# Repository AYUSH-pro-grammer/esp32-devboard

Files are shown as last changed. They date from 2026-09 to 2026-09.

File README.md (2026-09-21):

# ESP32-S2 Development Board

Development board built using Espressif ESP32-S2FH4 with USB-C, two WS2812B LEDs, 3.3V LDO and GPIO headers, which have 15 pins on both sides.

## Reasons for creating this project

I created this board because I want to get experience in designing a PCB and build my own ESP32 board. I was interested in building the schematic, routing the PCB and putting everything together.

### How it works

The board receives 5V from USB-C port and uses 3.3V LDO to power the ESP32-S2 module.
The ESP32-S2 is the core part of the board and can be programmed through USB-C.
GPIO pins are routed to two 1x15 headers to use them with jumper wires and breadboard.
WS2812B LEDs and a button were used to add some functionality to the board.

### 3D Model
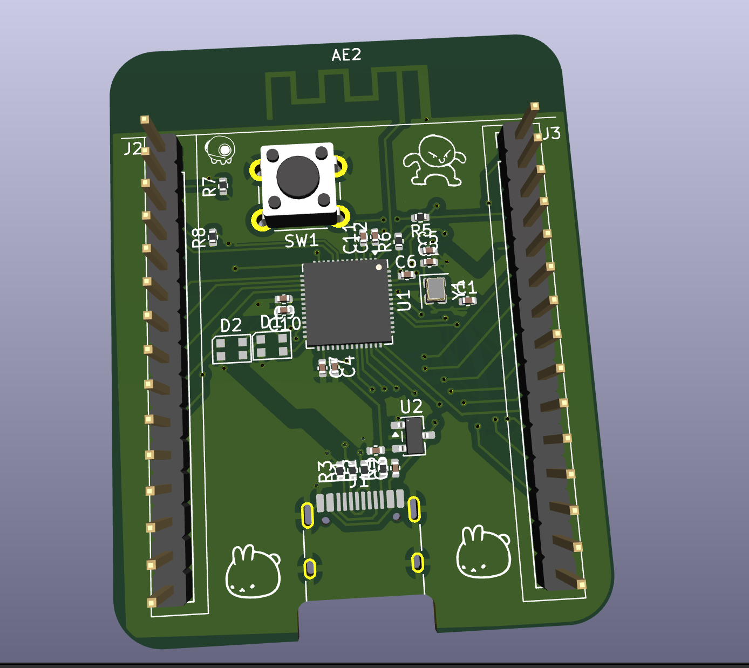
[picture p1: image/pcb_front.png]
PCB Front

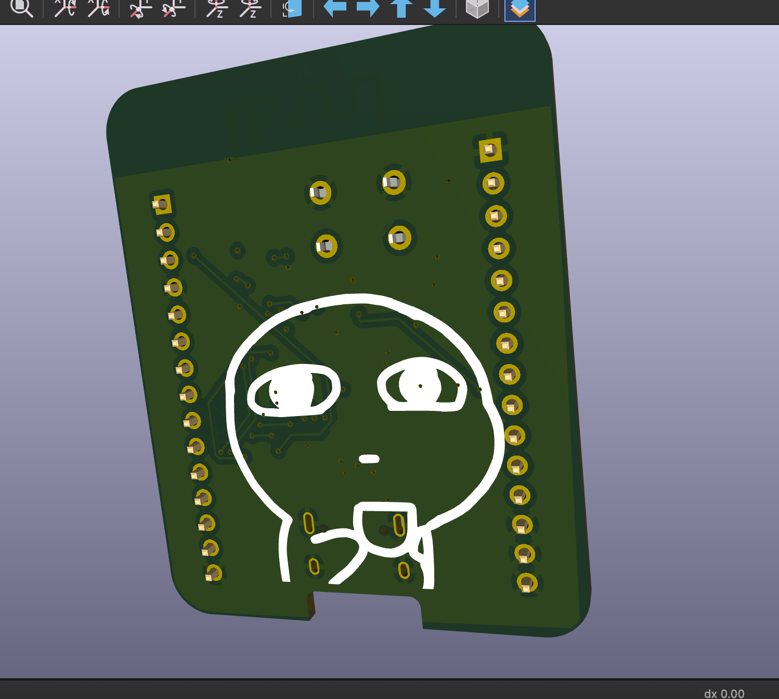
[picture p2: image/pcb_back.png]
PCB Back


### Schematics & Routing
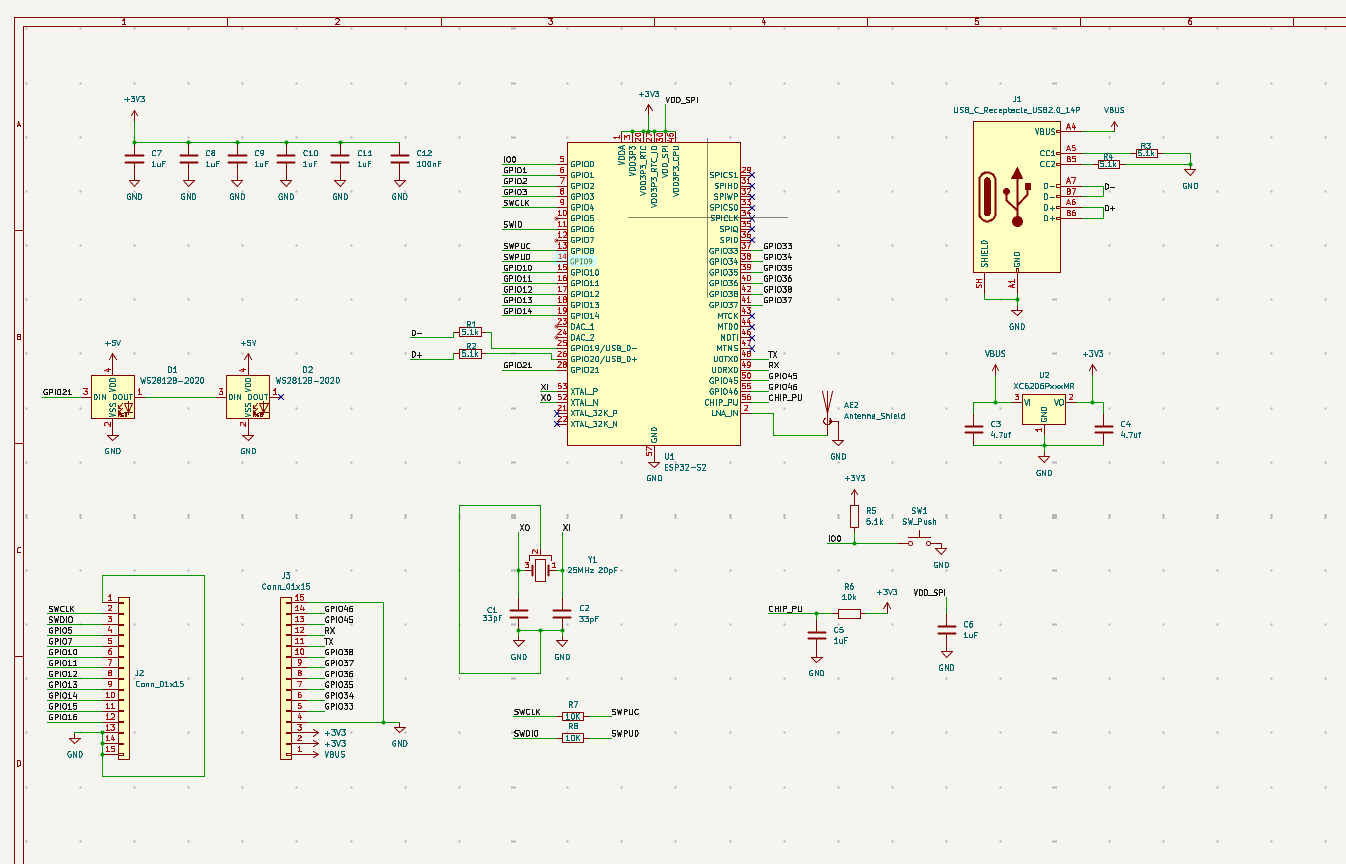
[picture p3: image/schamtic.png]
Schematic

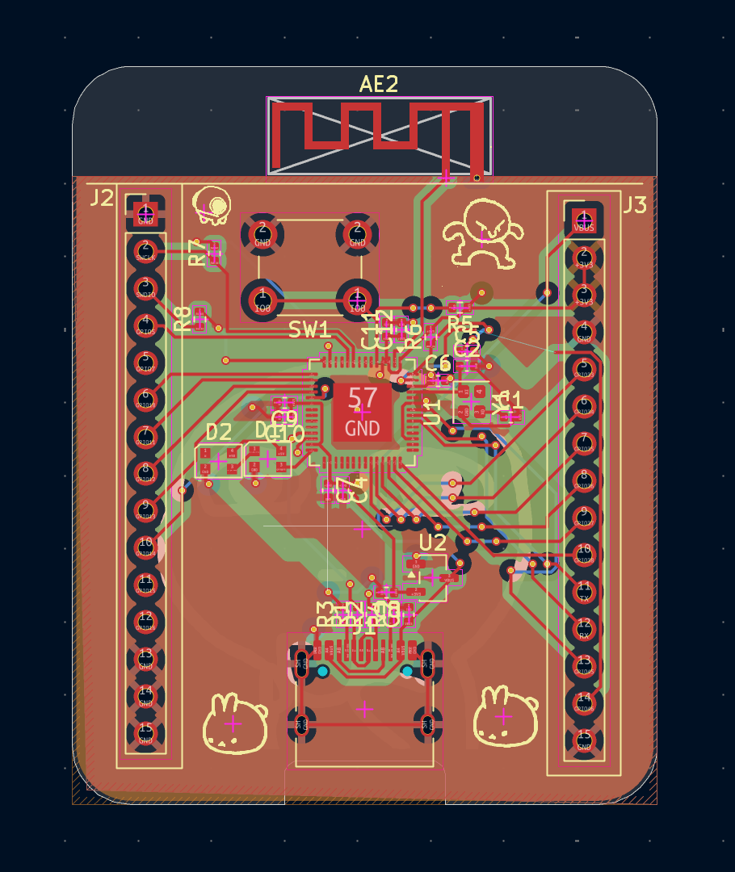
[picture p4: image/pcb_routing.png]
PCB Routing


## BOM Summary

| Qty | Component | Selected Part | Supplier | Link | MOQ | Unit Price (USD) | Order Cost (USD) |
| --: | --- | --- | --- | --- | --: | ---: | ---: |
| 1 | 25 MHz Crystal, 20 pF | SJK 7F25000E20UCG | SJK | [C252274](https://www.lcsc.com/product-detail/C252274.html) | 5 | $0.1139 | $0.57 |
| 2 | 33 pF Capacitor | FOJAN FCC0402N330J500AT | FOJAN | [C5137486](https://www.lcsc.com/product-detail/C5137486.html) | 100 | $0.0030 | $0.30 |
| 1 | 100 nF Capacitor | Samsung Electro-Mechanics CL05B104KO5NNNC | Samsung Electro-Mechanics | [C1525](https://www.lcsc.com/product-detail/C1525.html) | 100 | $0.0046 | $0.46 |
| 7 | 1 µF Capacitor | Samsung Electro-Mechanics CL05A105KA5NQNC | Samsung Electro-Mechanics | [C52923](https://www.lcsc.com/product-detail/C52923.html) |  50 | $0.0100 | $0.50 |
| 2 | 4.7 µF Capacitor | Samsung Electro-Mechanics CL05A475MP5NRNC | Samsung Electro-Mechanics | [C23733](https://www.lcsc.com/product-detail/C23733.html) |  50 | $0.0167 | $0.84 |
| 2 | WS2812B-2020 LED | XINGLIGHT XL-2020RGBC-2812B | XINGLIGHT | [C5349955](https://www.lcsc.com/product-detail/C5349955.html) | 5 | $0.1112 | $0.56 |
| 1 | 1 A / 12 V Resettable Fuse | R+O SMD0805-100-12 | R+O | [C46640991](https://www.lcsc.com/product-detail/C46640991.html) |  10 | $0.0435 | $0.44 |
| 1 | USB-C Receptacle | SHOU HAN TYPE-C16PIN | SHOU HAN | [C393939](https://www.lcsc.com/product-detail/C393939.html) |  10 | $0.0592 | $0.59 |
| 5 | 5.1 kΩ Resistor | UNI-ROYAL 0402WGF5101TCE | UNI-ROYAL | [C25905](https://www.lcsc.com/product-detail/C25905.html) | 100 | $0.0023 | $0.23 |
| 3 | 10 kΩ Resistor | UNI-ROYAL 0402WGF1002TCE | UNI-ROYAL | [C25744](https://www.lcsc.com/product-detail/C25744.html) | 100 | $0.0034 | $0.34 |
| 1 | Tactile Push Button | XUNPU TS-1088-AR02016 | XUNPU | [C720477](https://www.lcsc.com/product-detail/C720477.html) |  10 | $0.0516 | $0.52 |
| 1 | ESP32-S2FH4 | ESPRESSIF ESP32-S2FH4 | ESPRESSIF | [C2840995](https://www.lcsc.com/product-detail/C2840995.html) | 1 | $2.4574 | $2.46 |
| 1 | 3.3 V LDO | TOREX XC6206P332MR-G | TOREX | [C5446](https://www.lcsc.com/product-detail/C5446.html) | 5 | $0.1437 | $0.72 |

## Total

** BOM Total: $8.53 USD**

## Parts

| Designator | Part |
| --- | --- |
| C1, C2 | 33 pF |
| C3, C4, C5, C6, C7, C8, C9 | 1 µF |
| C10 | 100 nF |
| C39, C40 | 4.7 µF |
| D1, D2 | WS2812B-2020 |
| F1 | Resettable Fuse |
| J1 | USB-C Receptacle |
| R1, R2, R3, R4, R5 | 5.1 kΩ |
| R6, R7, R8 | 10 kΩ |
| SW1 | Tactile Push Button |
| U1 | ESP32-S2FH4 |
| U2 | XC6206P332MR-G |
| Y1 | 25 MHz Crystal |

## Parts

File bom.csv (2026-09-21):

SNO. | Quantity | Part Name | Link
0 | 2 | 33pF Capacitor SMD (0402) | https://www.lcsc.com/product-detail/C5137486.html
1 | 1 | 100nF Capacitor SMD (0402) | https://www.lcsc.com/product-detail/C1525.html
2 | 7 | 1uF Capacitor SMD (0402) | https://www.lcsc.com/product-detail/C52923.html
3 | 2 | 4.7uF Capacitor SMD (0402) | https://www.lcsc.com/product-detail/C23733.html
4 | 2 | WS2812B-2020 Addressable RGB LED | https://www.lcsc.com/product-detail/C5349955.html
5 | 1 | 12V 1A Resettable Fuse SMD (0805) | https://www.lcsc.com/product-detail/C46640991.html
6 | 1 | USB-C Receptacle USB 2.0 16-Pin | https://www.lcsc.com/product-detail/C393939.html
7 | 5 | 5.1kΩ Resistor SMD (0402) | https://www.lcsc.com/product-detail/C25905.html
8 | 3 | 10kΩ Resistor SMD (0402) | https://www.lcsc.com/product-detail/C25744.html
9 | 1 | TS-1088-AR02016 Tactile Switch | https://www.lcsc.com/product-detail/C720477.html
10 | 1 | ESP32-S2FH4 | https://www.lcsc.com/product-detail/C2840995.html
11 | 1 | XC6206P332MR-G 3.3V LDO Voltage Regulator (SOT-23-3) | https://www.lcsc.com/product-detail/C5446.html
12 | 1 | 25MHz 20pF Crystal SMD (2016) | https://www.lcsc.com/product-detail/C252274.html

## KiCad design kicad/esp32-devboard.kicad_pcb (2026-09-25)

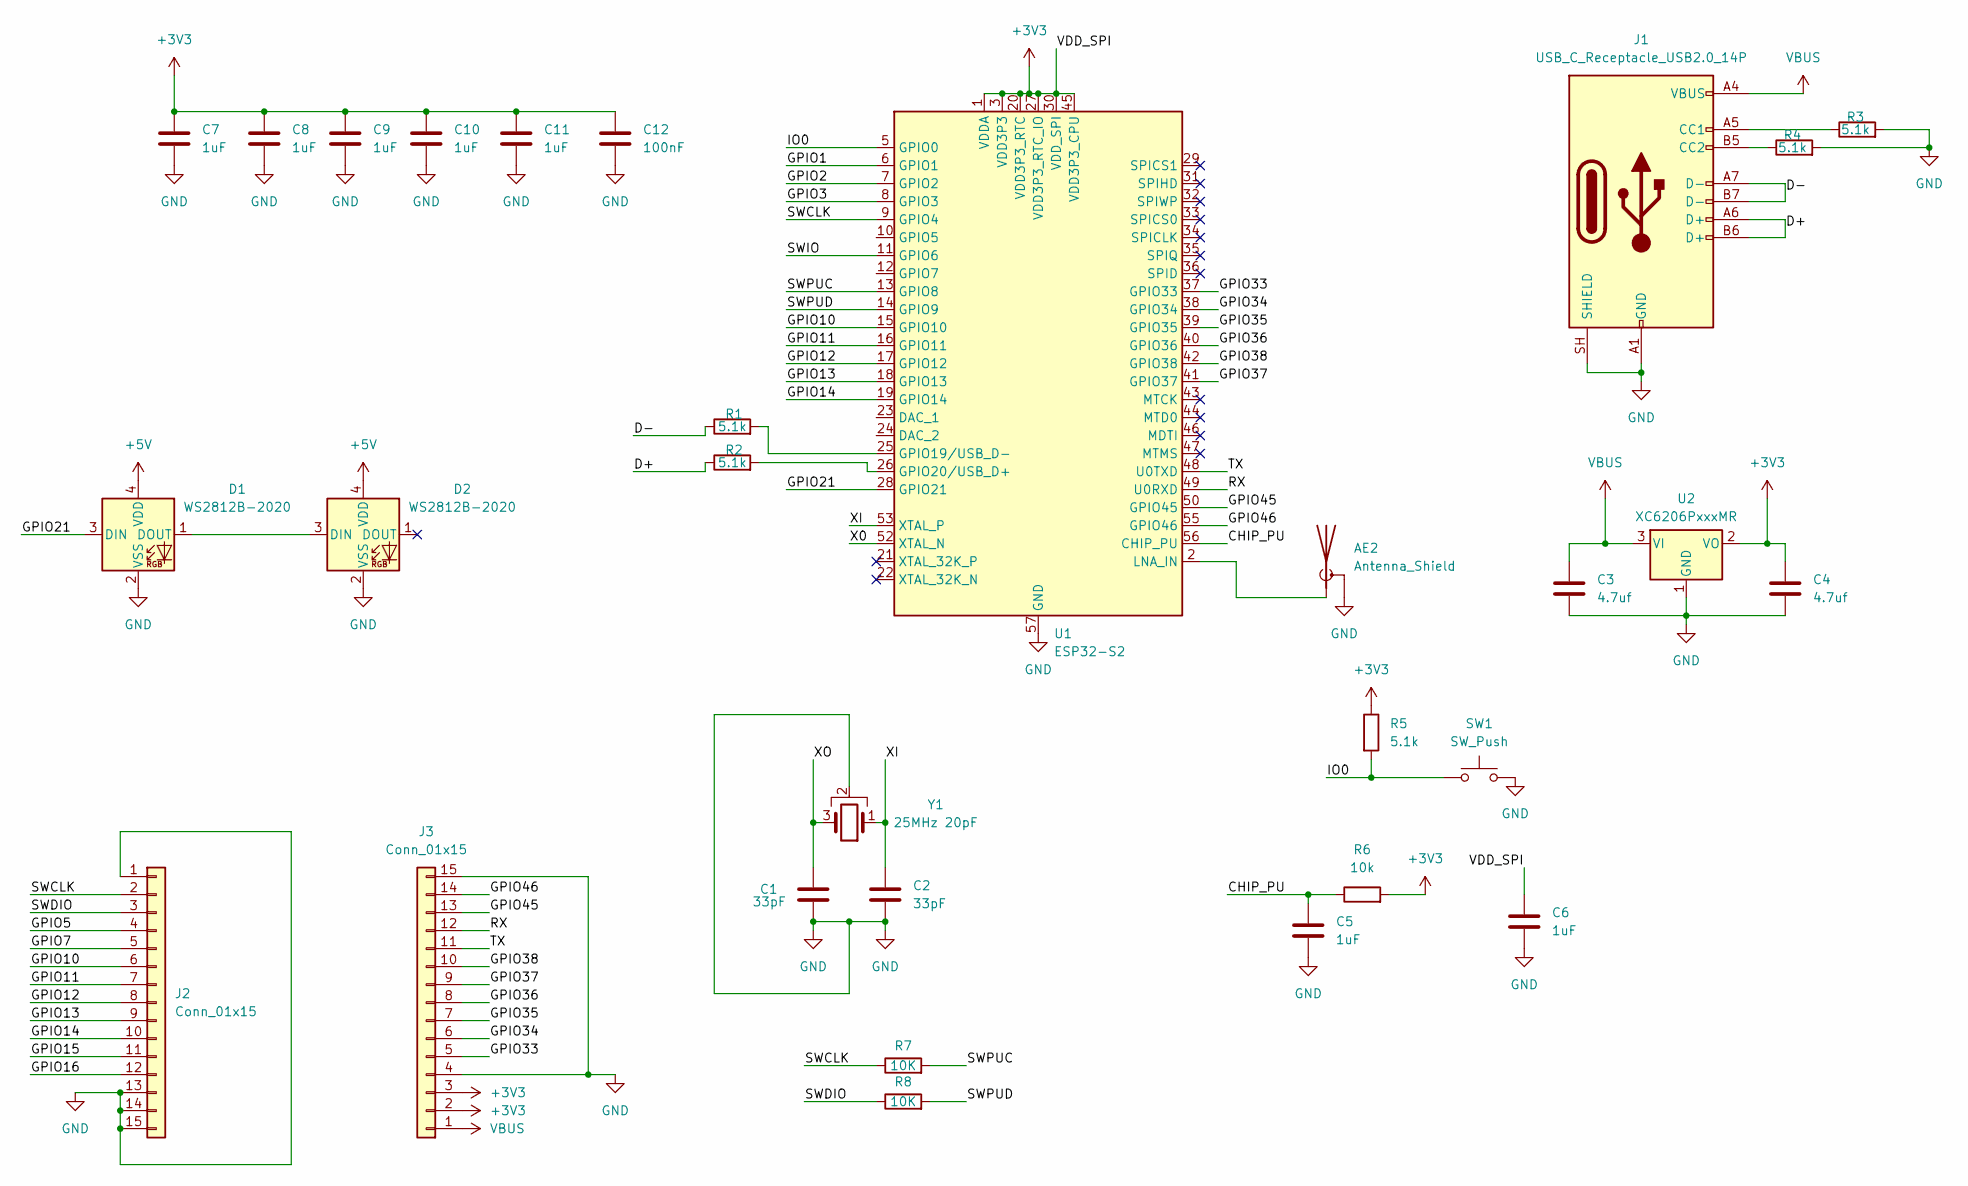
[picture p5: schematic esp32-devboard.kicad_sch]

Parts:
AE2: Antenna_Shield; Texas_SWRA117D_2.4GHz_Left
C1, C2: 33pF; C_0402_1005Metric
C3, C4: 4.7uf; C_0402_1005Metric
C5, C6, C7, C8, C9, C10, C11: 1uF; C_0402_1005Metric
C12: 100nF; C_0402_1005Metric
D1, D2: WS2812B-2020; LED_WS2812B-2020_PLCC4_2.0x2.0mm
J1: USB_C_Receptacle_USB2.0_14P; USB_C_Receptacle_HRO_TYPE-C-31-M-12
J2, J3: Conn_01x15; PinHeader_1x15_P2.54mm_Vertical
R1, R2, R3, R4, R5: 5.1k; R_0402_1005Metric
R6: 10k; R_0402_1005Metric
R7, R8: 10K; R_0402_1005Metric
SW1: SW_Push; SW_PUSH_6mm
U1: ESP32-S2; QFN-56-1EP_7x7mm_P0.4mm_EP4x4mm
U2: XC6206PxxxMR; SOT-23-3
Y1: 25MHz 20pF; Crystal_SMD_2016-4Pin_2.0x1.6mm

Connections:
+3V3: C4.1, C6.1, C7.1, C8.1, C9.1, C10.1, C11.1, C12.1, J3.2, J3.3, R5.1, R6.2, U1.1 (VDDA), U1.3 (VDD3P3), U1.4 (VDD3P3), U1.20 (VDD3P3_RTC), U1.27 (VDD3P3_RTC_IO), U1.30 (VDD_SPI), U1.45 (VDD3P3_CPU), U1.51 (VDDA), U1.54 (VDDA), U2.2 (VO)
+5V: D1.4 (VDD), D2.4 (VDD)
/CHIP_PU: C5.1, R6.1, U1.56 (CHIP_PU)
/D+: J1.A6 (D+), J1.B6 (D+), R2.1
/D-: J1.A7 (D-), J1.B7 (D-), R1.1
/GPIO1: U1.6 (GPIO1)
/GPIO2: U1.7 (GPIO2)
/GPIO3: U1.8 (GPIO3)
/GPIO5: J2.4
/GPIO7: J2.5
/GPIO10: J2.6, U1.15 (GPIO10)
/GPIO11: J2.7, U1.16 (GPIO11)
/GPIO12: J2.8, U1.17 (GPIO12)
/GPIO13: J2.9, U1.18 (GPIO13)
/GPIO14: J2.10, U1.19 (GPIO14)
/GPIO15: J2.11
/GPIO16: J2.12
/GPIO21: D1.3 (DIN), U1.28 (GPIO21)
/GPIO33: J3.5, U1.37 (GPIO33)
/GPIO34: J3.6, U1.38 (GPIO34)
/GPIO35: J3.7, U1.39 (GPIO35)
/GPIO36: J3.8, U1.40 (GPIO36)
/GPIO37: J3.9, U1.41 (GPIO37)
/GPIO38: J3.10, U1.42 (GPIO38)
/GPIO45: J3.13, U1.50 (GPIO45)
/GPIO46: J3.14, U1.55 (GPIO46)
/IO0: R5.2, SW1.1, U1.5 (GPIO0)
/RX: J3.12, U1.49 (U0RXD)
/SWCLK: J2.2, R7.1, U1.9 (GPIO4)
/SWDIO: J2.3, R8.1
/SWIO: U1.11 (GPIO6)
/SWPUC: R7.2, U1.13 (GPIO8)
/SWPUD: R8.2, U1.14 (GPIO9)
/TX: J3.11, U1.48 (U0TXD)
/X0: U1.52 (XTAL_N)
/XI: C2.1, U1.53 (XTAL_P), Y1.1
/XO: C1.1, Y1.3
GND: AE2.2 (Shield), C1.2, C2.2, C3.2, C4.2, C5.2, C6.2, C7.2, C8.2, C9.2, C10.2, C11.2, C12.2, D1.2 (VSS), D2.2 (VSS), J1.A1 (GND), J1.A12 (GND), J1.B1 (GND), J1.B12 (GND), J1.SH (SHIELD), J2.1, J2.13, J2.14, J2.15, J3.4, J3.15, R3.2, R4.2, SW1.2, U1.57 (GND), U2.1 (GND), Y1.2
unnamed: AE2.1 (A), U1.2 (LNA_IN)
unnamed: D1.1 (DOUT), D2.3 (DIN)
unnamed: J1.A5 (CC1), R3.1
unnamed: J1.B5 (CC2), R4.1
unnamed: R1.2, U1.25 (GPIO19/USB_D-)
unnamed: R2.2, U1.26 (GPIO20/USB_D+)
VBUS: C3.1, J1.A4 (VBUS), J1.A9 (VBUS), J1.B4 (VBUS), J1.B9 (VBUS), J3.1, U2.3 (VI)

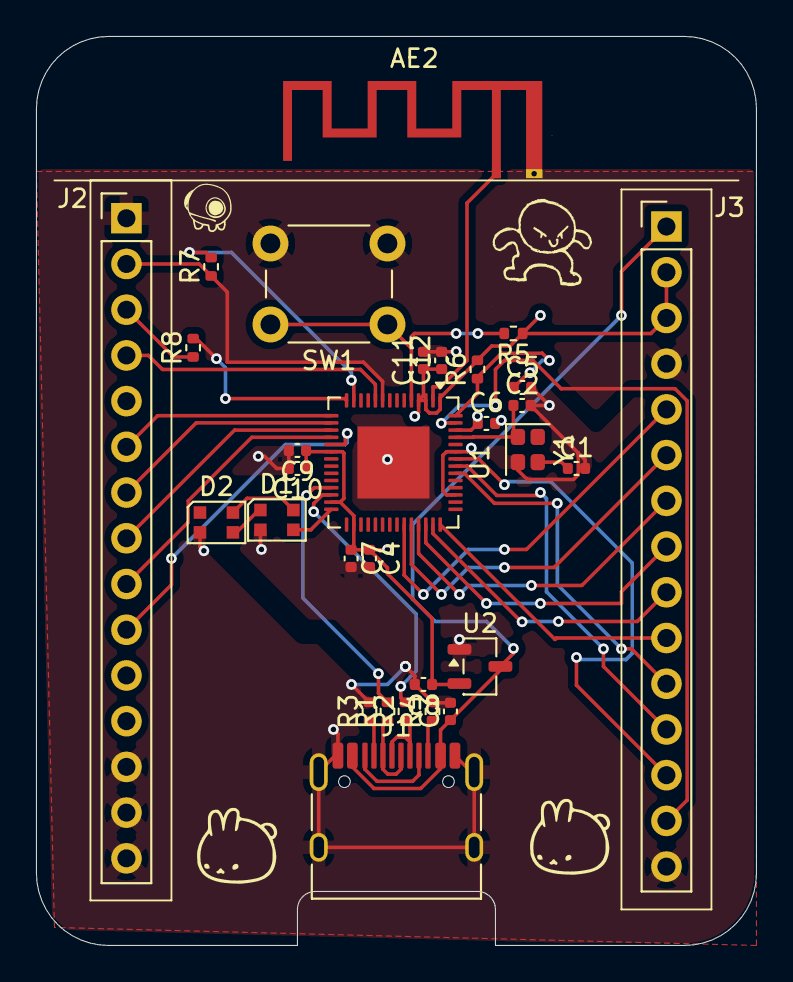
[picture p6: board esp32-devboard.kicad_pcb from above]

Board: 4 copper layers, 40.0 x 50.5 mm, 30 parts (0 on the bottom side), 36 nets.

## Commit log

2026-09-21 kicad folder
2026-09-21 updated bomcsv
    [bom.csv]
